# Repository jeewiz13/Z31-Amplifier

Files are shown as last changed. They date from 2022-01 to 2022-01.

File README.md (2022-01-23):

# Z31-Amplifier
New Amplifier that fits into stock Z31 Amplifier Housing
This isn't for the faint of heart.  This requires desoldering skills as the original header and DIN socket are reused.
It could use a few tweaks with spacing of the amplifier chips. They are off a little left or right. The footprints could also use a few tweaks as well. Works as is though. 
I originally thought the amplifier chips wouldn't fit inbetween the original metal mounting clamps.  They do but I was going to make an adapter out of aluminum to have it sink to the case. This spacing is rather large.  This spacing should be resolved if another version were to be made.

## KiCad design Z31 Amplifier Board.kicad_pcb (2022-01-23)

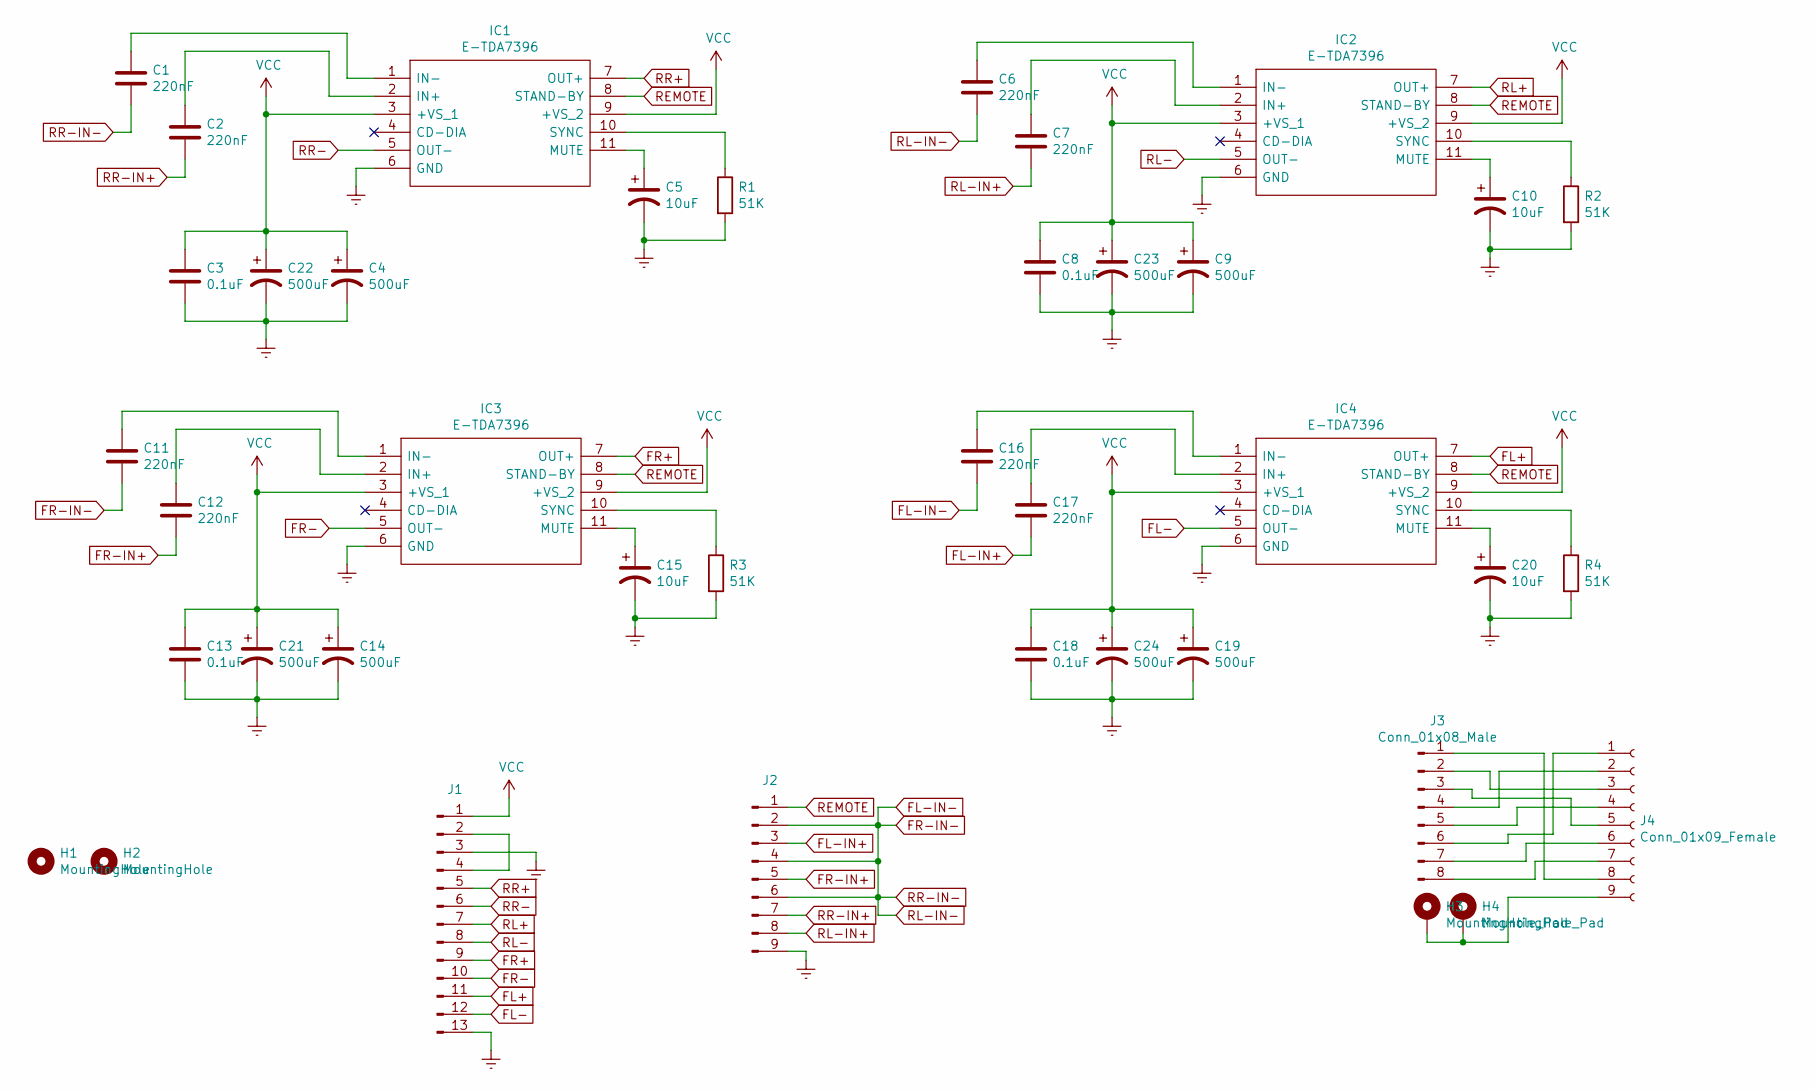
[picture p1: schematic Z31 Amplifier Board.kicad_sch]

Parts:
C1, C2, C6, C7, C11, C12, C16, C17: 220nF; C_Rect_L7.2mm_W2.5mm_P5.00mm_FKS2_FKP2_MKS2_MKP2
C3, C8, C13, C18: 0.1uF; C_Disc_D3.8mm_W2.6mm_P2.50mm
C4, C9, C14, C19, C21, C22, C23, C24: 500uF; CP_Radial_D10.0mm_P5.00mm
C5, C10, C15, C20: 10uF; CP_Radial_D5.0mm_P2.00mm
H1, H2: MountingHole; MountingHole_4.3mm_M4_ISO14580_Pad_TopBottom
H3, H4: MountingHole_Pad; MountingHole_2.5mm_Pad
IC1, IC2, IC3, IC4: E-TDA7396; TO170P500X1960X2210-11P; Mouser Part Number 511-E-TDA7396
J1: Conn_01x13_Male; Z31 Big Connector
J2: Conn_01x09_Male; Z31 Input Connector
J3: Conn_01x08_Male; 300ZX DIN Board Edge Connector
J4: Conn_01x09_Female; Din-8 Socket
R1, R2, R3, R4: 51K; R_Axial_DIN0309_L9.0mm_D3.2mm_P15.24mm_Horizontal

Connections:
Earth: C3.2, C4.2, C5.2, C8.2, C9.2, C10.2, C13.2, C14.2, C15.2, C18.2, C19.2, C20.2, C21.2, C22.2, C23.2, C24.2, IC1.6 (GND), IC2.6 (GND), IC3.6 (GND), IC4.6 (GND), J1.3, J1.13, J2.9, R1.2, R2.2, R3.2, R4.2
FL+: IC4.7 (OUT+), J1.11
FL-: IC4.5 (OUT-), J1.12
FL-IN+: C17.2, J2.3
FL-IN-: C1.2, C6.2, C11.2, C16.2, J2.2, J2.4, J2.6
FR+: IC3.7 (OUT+), J1.9
FR-: IC3.5 (OUT-), J1.10
FR-IN+: C12.2, J2.5
unnamed: C1.1, IC1.1 (IN-)
unnamed: C2.1, IC1.2 (IN+)
unnamed: C5.1, IC1.11 (MUTE)
unnamed: C6.1, IC2.1 (IN-)
unnamed: C7.1, IC2.2 (IN+)
unnamed: C10.1, IC2.11 (MUTE)
unnamed: C11.1, IC3.1 (IN-)
unnamed: C12.1, IC3.2 (IN+)
unnamed: C15.1, IC3.11 (MUTE)
unnamed: C16.1, IC4.1 (IN-)
unnamed: C17.1, IC4.2 (IN+)
unnamed: C20.1, IC4.11 (MUTE)
unnamed: H3.1, H4.1, J4.9
unnamed: IC1.10 (SYNC), R1.1
unnamed: IC2.10 (SYNC), R2.1
unnamed: IC3.10 (SYNC), R3.1
unnamed: IC4.10 (SYNC), R4.1
unnamed: J1.2, J1.4
unnamed: J3.1, J4.8
unnamed: J3.2, J4.3
unnamed: J3.3, J4.5
unnamed: J3.4, J4.2
unnamed: J3.5, J4.4
unnamed: J3.6, J4.1
unnamed: J3.7, J4.6
unnamed: J3.8, J4.7
REMOTE: IC1.8 (STAND-BY), IC2.8 (STAND-BY), IC3.8 (STAND-BY), IC4.8 (STAND-BY), J2.1
RL+: IC2.7 (OUT+), J1.7
RL-: IC2.5 (OUT-), J1.8
RL-IN+: C7.2, J2.8
RR+: IC1.7 (OUT+), J1.5
RR-: IC1.5 (OUT-), J1.6
RR-IN+: C2.2, J2.7
VCC: C3.1, C4.1, C8.1, C9.1, C13.1, C14.1, C18.1, C19.1, C21.1, C22.1, C23.1, C24.1, IC1.3 (+VS_1), IC1.9 (+VS_2), IC2.3 (+VS_1), IC2.9 (+VS_2), IC3.3 (+VS_1), IC3.9 (+VS_2), IC4.3 (+VS_1), IC4.9 (+VS_2), J1.1

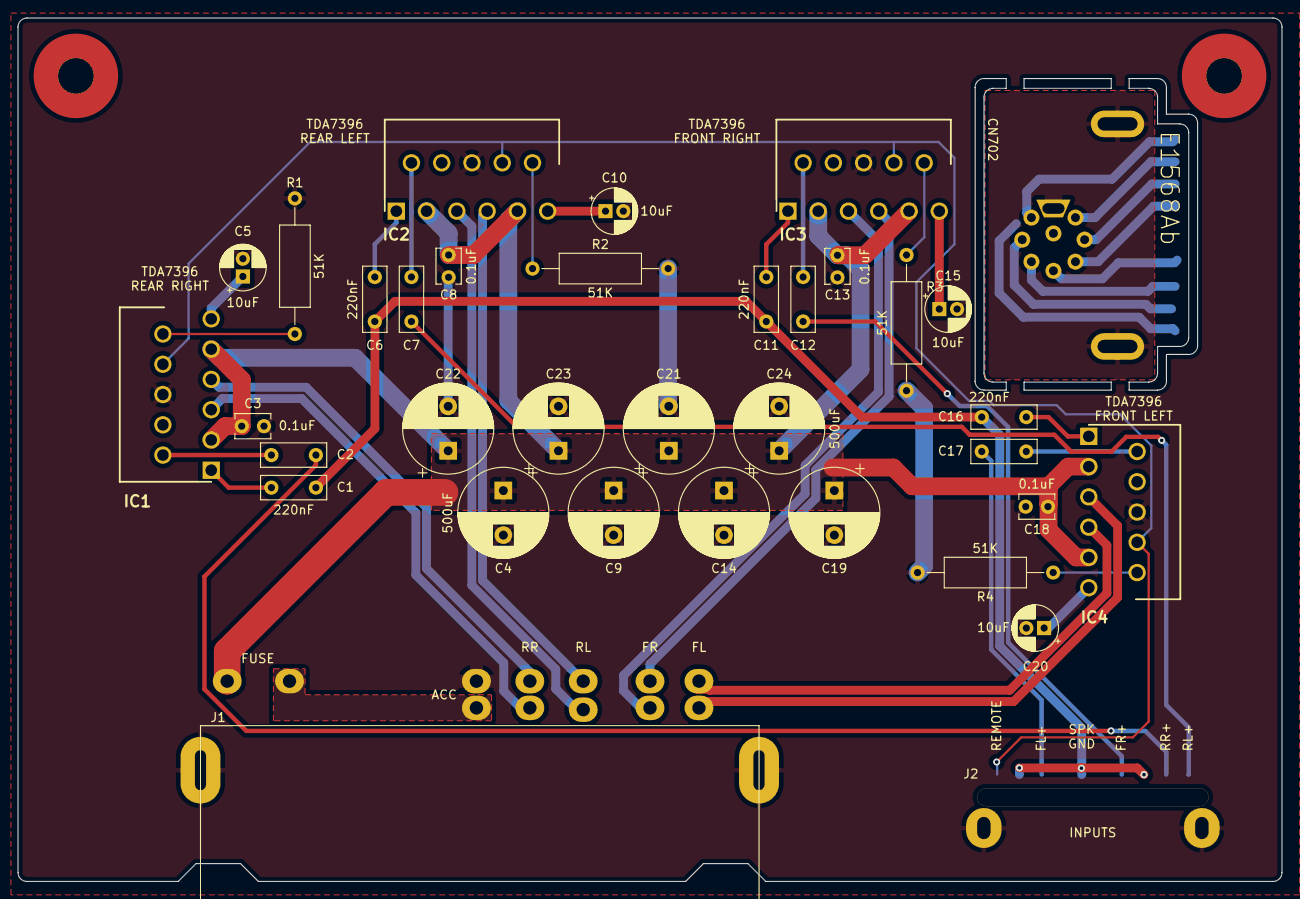
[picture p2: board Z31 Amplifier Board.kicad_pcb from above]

Board: 2 copper layers, 142.0 x 97.0 mm, 40 parts (0 on the bottom side), 42 nets.

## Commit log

2022-01-23 Create footprint
2022-01-23 Create bom
2022-01-23 Create gerber
